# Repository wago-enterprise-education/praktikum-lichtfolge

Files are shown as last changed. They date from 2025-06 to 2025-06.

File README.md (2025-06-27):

# Praktikum – Lichtfolge

Bau einer kleinen Platine als handheld Spielekonsole.

- **Dauer:** ~20 Min. (ohne Auf- und Abbbauzeit)

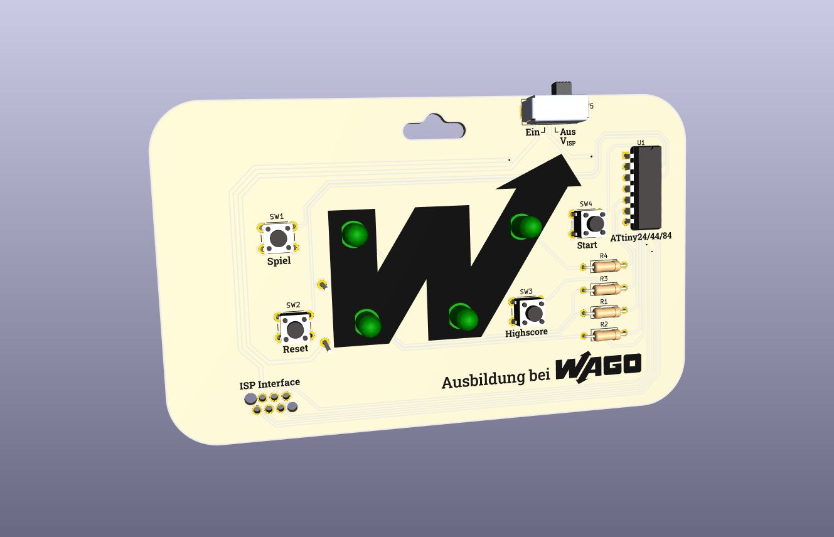
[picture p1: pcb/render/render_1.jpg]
Platine Praktikum-Lichtfolge
</br>

## Quick Links
- **Dokumentation:** [wago-enterprise-education.github.io/praktikum-lichtfolge/](https://wago-enterprise-education.github.io/praktikum-lichtfolge/)
- **Bestückungsplan:** [docs/Bestueckungsplan_praktikum-lichtfolge_v1.0.html](https://wago-enterprise-education.github.io/praktikum-lichtfolge/Bestueckungsplan_praktikum-lichtfolge_v1.0.html)
- **Schaltplan:** [pcb/schematics_praktikum-lichtfolge.pdf](pcb/schematics_praktikum-lichtfolge.pdf)
- **Materialliste (BOM):** [docs/bom/ibom_praktikum-lichtfolge_v1.0.html](https://wago-enterprise-education.github.io/praktikum-lichtfolge/bom/ibom_praktikum-lichtfolge_v1.0.html)

## Ansprechpartner
- [Tobias Lauxtermann](mailto:tobias.lauxtermann@wago.com)

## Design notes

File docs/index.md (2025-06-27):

---
layout: post
title: Praktikum – Lichtfolge
lang: de
---

# Praktikum – Lichtfolge

1. [Bauanleitung](#bauanleitung) 
2. [Upload des Programmcodes](#upload-des-programmcodes)
3. [Programming Guide](#programming-guide)

## Bauanleitung

{:.info}
Einen interaktiven Bestückungsplan mit Bauteilliste findest du hier: **[Bestückungsplan ➡️](Bestueckungsplan_praktikum-lichtfolge_v1.0.html)**

Beginne beim Bestücken und anschließenden Löten der Platine mit den **niedrigsten Bauteilen**. Sonst kann es eventuell schwierig werden diese später zu erreichen. Bei dieser Platine ist es wichtig den **Batteriehalter auf der Rückseite als letztes** einzubauen, da anschließend einige Lötstellen nicht mehr erreichbar sind. Dies ist auch das einzige Bauteil, das nicht auf der Vorderseite bestückt wird.

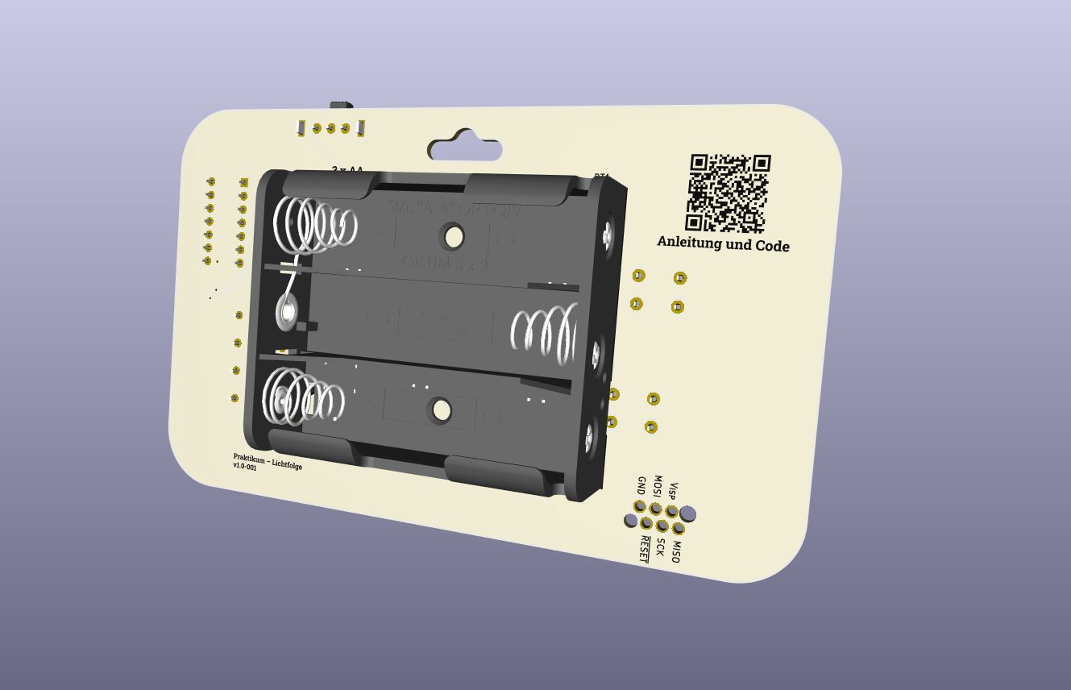
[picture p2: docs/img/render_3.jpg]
Platine Praktikum-Lichtfolge

Gelötet wird bei THT-Bauteilen (Through Hole Technology, deutsch Durchsteckmontage) immer auf der Nicht-Bestückungsseite. Also muss die Platine nach dem Einsetzen einmal gedreht werden. Damit die Bauteile dabei nicht herausfallen, sollten die Komponenten provisorisch fixiert werden. Manche Platinenhalter haben dafür bereits eine Vorrichtung (vgl. Abb.). Eine einfache Alternative ist Malerkrepp (leicht lösbares Klebeband), das über die Bauteile geklebt wird. Dabei ist es sinnvoll, **nicht alle Bauteile auf einmal** zu bestücken und anschließend zu löten, sondern in Gruppen ähnlicher und benachbarter Komponenten zu arbeiten. Die Taster und der Schiebeschalter auf dieser Platine müssen zum Löten nicht fixiert werden.

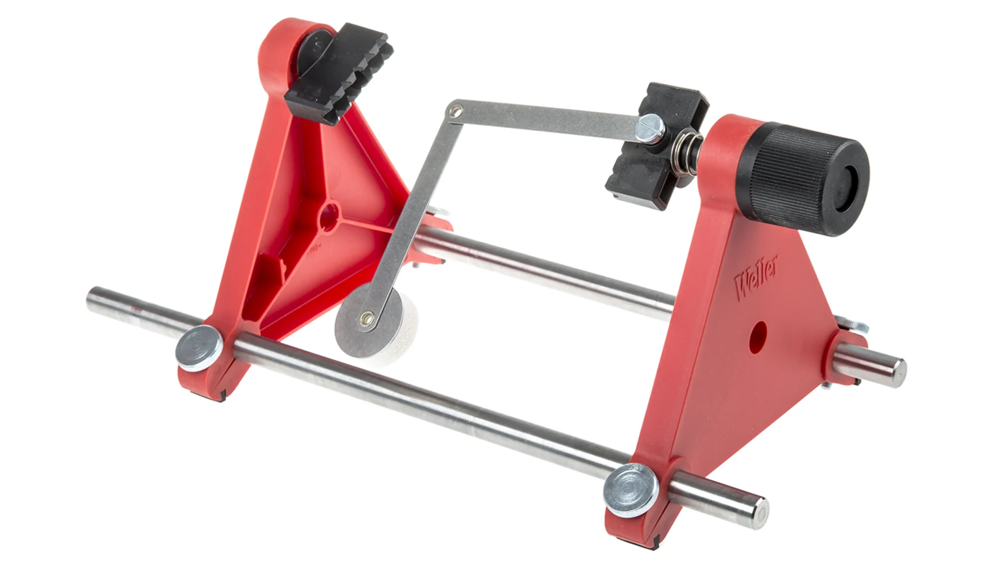
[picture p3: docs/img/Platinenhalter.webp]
Platinenhalter


Da wir bleifreies Lötzinn verwenden, sollte der Lötkolben etwas höher eingestellt werden. **330 bis 360°C** sind ein guter Richtwert. Für Lötstellen, die mit einer großen Kupferfläche verbunden sind, beispielsweise GND-Flächen, können auch 380°C sinnvoll sein. Mit steigender Temperatur sinkt jedoch die aktive Dauer des Flussmittels im Lötzinn deutlich, was wiederum das Löten erschwert. Mehr als 380°C sollten nicht eingestellt werden, da dies die Lebensdauer der Lötspitze stark verringert.

Achte beim Löten darauf zunächst **das Lötpad auf der Platine und das Beinchen des entsprechenden Bauteils gleichzeitig zu erhitzen** und erst nach einigen Sekunden Lötzinn hinzuzugeben. Geduldig sein sorgt hier für bessere Ergebnisse. Halte anschließend den Lötkolben noch kurz an die Lötstelle bis das Lötzinn schön geflossen und das gesamte Lötpad bedeckt ist. Sollte das hinzugegebene Lötzinn nicht ausreichen, kann hier auch noch etwas nachgeführt werden. 

Anschließend können mit einem Seitenschneider die überstehenden Drähte abgeknipst werden. Achte darauf dies nicht zu tief zu tun und **nur das Beinchen zu durchtrennen**, nicht die Lötstelle.

Bevor der Batteriehalter auf der Rückseite eingesetzt wird (dieser wird entsprechend auf der Vorderseite verlötet), klebe etwas **doppelseitiges Schaumstoffklebeband** darauf, um für zusätzliche mechanische Stabilität und Abstand zu den anderen Lötstellen zu sorgen.

## Upload des Programmcodes

{:.info}
**[Programmcode herunterladen ➡️](https://github.com/wago-enterprise-education/praktikum-lichtfolge/blob/main/code/praktikum-lichtfolge/praktikum-lichtfolge.ino)**

Die Platine verwendet für die Spiellogik einen Mikrocontroller aus der [ATtinyx4A ↗️](https://ww1.microchip.com/downloads/en/DeviceDoc/ATtiny24A-44A-84A-DataSheet-DS40002269A.pdf){:target="_blank" rel="noopener"} Reihe. Um genügend Speicherplatz für mehrere Spiele bereitzustellen, kommt der **ATtiny84A** zum Einsatz. Die Mikrocontrollerreihe verfügt über einen internen Oszillator für den Prozessortakt und kann über ein ISP-Interface programmiert werden. Der Eingangsspannungsbereich beträgt 1,8 bis 5,5 V.

Programmieren kann man den Mikrocontroller beispielsweise über die MPLAB® X IDE von Microchip, aber auch über Tools wie avrdude oder Arduino.

Bei unseren Praktikumsmodulen verwenden wir die [Arduino IDE ↗️](https://www.arduino.cc/en/software/){:target="_blank" rel="noopener"}. Dabei handelt es sich um eine open source Entwicklungsumgebung mit einer großen und aktiven online Community mit vielen Ressourcen zum Lernen. Über den darin integrierten Boards Manager kann der [ATTinyCore ↗️](https://github.com/SpenceKonde/ATTinyCore){:target="_blank" rel="noopener"} installiert werden, der es ermöglicht AVR-basierte Mikrocontroller wie den ATtiny84A zu programmieren.

Dafür wird ein zusätzliches Gerät, ein **ISP-Programmer**, benötigt. Es kann jedoch auch beispielsweise ein Arduino Uno hierfür verwendet werden. Hier findest du eine Anleitung dazu: [Programming ATtiny with Arduino code ↗️](https://wolles-elektronikkiste.de/en/programming-attiny-with-arduino-code){:target="_blank" rel="noopener"}. Die entsprechenden ISP-Verbindungen sind auf der Rückseite der Platine gekennzeichnet an die du übergangsweise Kabel anlöten kannst. 

Für eine schnelle und unkomplizierte Programmierung wurde im WAGO Ausbildungsbereich zusätzlich ein [ISP UPDI Programmer](https://wago-enterprise-education.github.io/isp-updi-programmer/) als Aufsatz für einen Arduino Uno entwickelt. Über lötfreie Steckverbinder kann hiermit der Mikrocontroller auf der Platine programmiert werden.

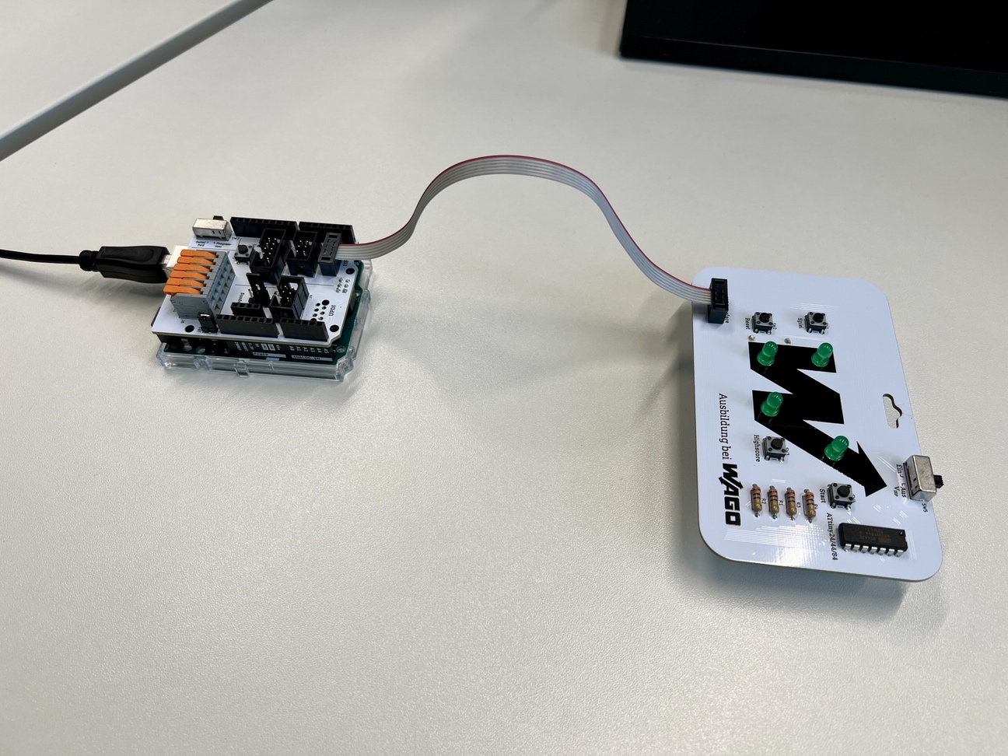
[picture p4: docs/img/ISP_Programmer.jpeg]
Programmierung über ISP


### Kurzanleitung
0. Falls nicht schon geschehen: AurduinoISP Sketch `File > Examples > 11.ArduinoISP > Arduino ISP` auf den Arduino Uno, Leonardo oder Mega laden. Beim WAGO ISP UPDI Programmer muss eventuell der linke Jumper entfernt werden. 
1. Arduino Projekt ([praktikum-lichtfolge](https://github.com/wago-enterprise-education/praktikum-lichtfolge/blob/main/code/praktikum-lichtfolge/praktikum-lichtfolge.ino)) öffnen
2. Mikrocontroller auswählen `Tools > Board: … > ATTinyCore > ATtiny24/44/84(a) (No bootloader)`
3. Standardeinstellungen können bestehen bleiben (vgl. Abb.)
4. `Tools > Programmer > Arduino as ISP` auswählen
5. `Tools > Port` und den COM-Port auswählen mit dem der Arduino verbunden ist
6. `Tools > Burn Bootloader` ausführen (muss bei Änderung der Clock Source erneut durchgeführt werden)
7. Upload (Pfeil oben links)

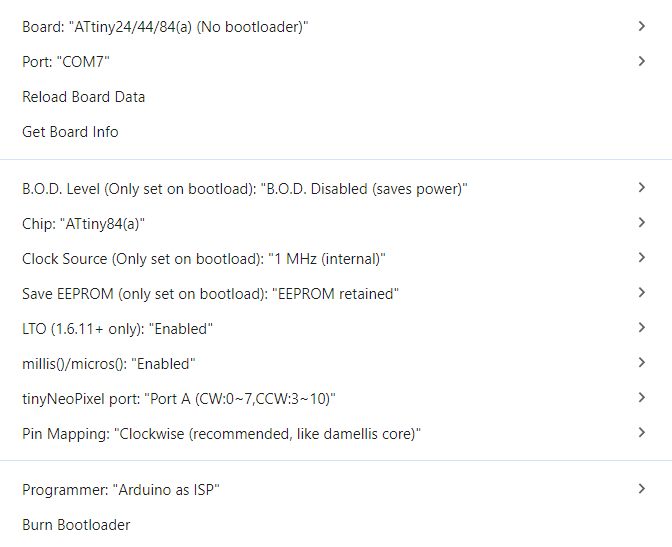
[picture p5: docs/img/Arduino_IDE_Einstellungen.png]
Einstellungen in der Arduino IDE


## Spielanleitung
Das UI (User Interface, deutsch Benutzeroberfläche) der Platine besteht aus 4 LEDs und 4 Tastern über die das Menü und die Spiele umgesetzt wurden. Im Folgenden wird kurz auf die verschiedenen Funktionen eingegangen.

### Spiel auswählen
Über **Taster 1 („Spiel“)** kann ein Spiel ausgewählt werden. Bei [Spiel 1](#spiele) muss sich eine immer länger werdende Lichtfolge gemerkt werden, [Spiel 2](#spiele) ist ein Reaktionsspiel, bei dem man möglichst schnell die LEDs „wegklicken“ muss, bei [Spiel 3](#spiele) handelt es sich um einen digitalen Würfel und [Spiel Nummer 4](#programmcode-für-spiel-4) ist frei. Hier kannst du mithilfe des [Programming Guides](#programming-guide) dein eigenes Spiel entwickeln. Selbstverständlich steht es dir aber frei alle Spiele anzupassen oder ganz auszutauschen.

### Spiel starten
Über **Taster 4 („Start“)** kann das aktuell ausgewählte Spiel gestartet werden.

### Highscore anzeigen
**Taster 3** zeigt den aktuellen Highscore des Spiels an. Jede LED steht dabei für die Ziffer einer vierstelligen Zahl. Blinkt beispielsweise LED 3 1-Mal und danach LED 4 6-Mal, beträgt der Highscore für dieses Spiel 16.

### Highscore zurücksetzen
Um den Highscore eines Spiels zurückzusetzen, halte **Taster 2 („Reset“)** mindestens 5 Sekunden gedrückt.

### Spiele

In der folgenden Tabelle werden die verfügbaren Spiele kurz erläutert.

|#| Spiel | Beschreibung |
|-|---|---|
|**1**|**Lichtfolge**|Nach einer kurzen Animation, um den Start des Spiels zu signalisieren, leuchtet eine zufällige LED auf. Merke dir diese und drücke den zugehörigen Taster. Anschließend leuchtet die gleiche LED erneut auf, gefolgt von einer weiteren zufälligen LED (es kann auch die gleiche noch mal sein). Daraufhin drückst du wieder nacheinander die entsprechenden Taster. Die Folge wird so immer länger, bis du dir die Reihenfolge nicht mehr merken kannst und einen Fehler machst. Dann blinken alle LEDs kurz viermal auf und dir wird deine erreichte Punktzahl angezeigt (siehe Unterkapitel [Highscore anzeigen](#highscore-anzeigen)). Die Punktzahl entspricht hierbei der Länge der Lichtfolge. Wieviel kannst du dir merken?|
|**2**|**Reaktionstest**|Zu Beginn des Spiels leuchtet eine zufällige LED auf. Klicke schnellstmöglich auf den entsprechenden Taster, um sie auszuschalten. Anschließend leuchtet eine beliebige andere LED auf. Du hast 30 Sekunden Zeit, um so möglichst viele LED „wegzuklicken“. Jede LED gibt hierbei einen Punkt. Drückst du jedoch versehentlich auf einen falschen Taster, wird dir ein Punkt abgezogen. Das Minimum sind jedoch 0 Punkte. Wie gut sind deine Reaktionen?|
|**3**|**Würfeln**|Nach einer kurzen Zufallsanimation leuchten alle vier LEDs ein paar Mal auf. Dies entspricht der gewürfelten Zahl zwischen 1 und 6. Im Code kannst du den Zahlenbereich aber auch anpassen oder die Art der Darstellung ändern, sodass die Zahlen wie bei den Highscores angezeigt werden. So könnten auch zufällige Zahlen von 0 bis 9999 angezeigt werden.|
|**4**|**Frei**|Hier kannst du dein eigenes Spiel programmieren. Informationen dazu findest du im [Programming Guide](#programming-guide).|

## Programming Guide
In diesem Kapitel gibt es eine kurze Einführung dazu, wie du **selbst Spiele für die Platine programmieren** kannst. Grundlagen für das Programmieren in C++ (Arduino) werden dabei vorausgesetzt. Bei YouTube gibt es ansonsten viele einsteigerfreundliche Tutorials dazu, suche einfach nach *Arduino Tutorial* und schon nach kurzer Zeit solltest du in der Lage sein die LEDs nach deinen Vorgaben anzusteuern.

### Programmcode für Spiel 4
In der Funktion `playGame4()` kannst du deinen eigenen Code schreiben. Sie wird ausgeführt, wenn LED 4 leuchtet und Taster 4 („Start“) gedrückt wird. Aktuell wird hier nur die Funktion `errorAnimation()` aufgerufen, die kurz alle LEDs viermal aufleuchten lässt. Entferne diese Funktion testweise und ersetzte sie durch `startupAnimation()`. Anschließend erscheint beim Starten des Spiels die Animation, die auch beim Einschalten der Platine angezeigt wird.

### LEDs ansteuern
Die LEDs können über die Funktion `digitalWrite()` ein- oder ausgeschaltet werden. Die entsprechenden Pins sind in dem Array `leds` hinterlegt.

Um beispielsweise LED 1 leuchten zu lassen, schreibe: `digitalWrite(leds[0], HIGH)`.

{:.info}
Den Schaltplan der Platine, um zu sehen welche Pins des Mikrocontrollers womit verbunden sind, findest du hier: **[Schaltplan Praktikum – Lichtfolge ➡️](https://github.com/wago-enterprise-education/praktikum-lichtfolge/blob/main/pcb/schematics_praktikum-lichtfolge.pdf)**

### Taster abfragen
Zum Entprellen der Taster wird die Bibliothek [Bounce2 ↗️](https://github.com/thomasfredericks/Bounce2){:target="_blank" rel="noopener"} verwendet. Das **Entprellen von Tastern und Schaltern** ist notwendig, da bei deren Betätigung kleine Vibrationen entstehen, die dafür sorgen, dass kurzzeitig zwischen geschlossenem und geöffnetem Zustand gewechselt wird. Erst nach einigen Millisekunden stabilisiert sich der Zustand. Beim schnellen Abfragen der Taster mit einem Mikrocontroller, kann es dadurch zu **ungewollten Zustandsänderungen** kommen, die mithilfe der Bibliothek herausgefiltert werden.

Die Instanzen für die jeweiligen Taster sind in dem Array `buttons` abgelegt. Um beispielsweise den Zustand von Taster 1 zu aktualisieren, muss regelmäßig die Funktion `buttons[0].update()` aufgerufen werden. Dies geschieht nicht automatisch im Hintergrund. Zwischen zwei Abfragen des Zustands eines Tasters, muss also mindestens einmal die Update-Funktion aufgerufen werden, um ein anderes Ergebnis erhalten zu können. Zum Aktualisieren von allen vier Tastern auf einmal, kann die Funktion `updateButtons()` genutzt werden.

Die Bounce2 Bibliothek stellt einige Funktionen bereit, die das Arbeiten mit den Tastern vereinfacht. Hier eine Liste der gängigsten Methoden:

| Funktion | Beschreibung |
|---|---|
|`pressed()`|Gibt „true“ zurück, wenn der Taster seit dem letzten Update gedrückt wurde, sich also der Zustand von „nicht-gedrückt“ zu „gedrückt“ geändert hat|
|`isPressed()`|Gibt „true“ zurück, wenn der Taster seit dem letzten Update gedrückt wurde, sich also der Zustand von „nicht-gedrückt“ zu „gedrückt“ geändert hat|
|`released()`|Gibt „true“ zurück, wenn der Taster aktuell gedrückt ist|
|`currentDuration()`|Gibt die Zeit zurück, wie lange der aktuelle Zustand herrscht|
|`read()`|Gibt den aktuellen Zustand (HIGH, LOW) des Tasters zurück. LOW = gedrückt, HIGH = nicht gedrückt.|

Die komplette Dokumentation findest du [hier ↗️](https://github.com/thomasfredericks/Bounce2){:target="_blank" rel="noopener"}.

### Weitere nützliche Funktionen und Variablen

| Funktion | Beschreibung |
|---|---|
|`startupAnimation()`|Zeigt die Start-Animation an|
|`errorAnimation()`|Zeigt die Error-Animation an|
|`clearLEDs()`|Setzt alle LEDs auf LOW|
|`random(long n)`|Gibt eine pseudo zufällige natürliche Zahl von 0 bis n-1 zurück|
|`displayScore(uint16_t score)`|Zeigt den „score“ mithilfe der LEDs an|
|`enum Buttons {GAME, RESET, HIGHSCORE, START}`|Bietet die Möglichkeit die Indizes der Taster über den Namen ihrer Funktion im Menü zu referenzieren (`GAME = 0`, `RESET = 1`, …)|
|`enum Game {SIMON_SAYS, WHACK_A_MOLE, ROLL_DICE, GAME4}`|Bietet die Möglichkeit die Indizes der Spiele über ihre Namen zu referenzieren (`SIMON_SAYS = 0`, …) |
|`displayHighscore(Game game)`|Zeige den Highscore des entsprechenden Spiels an|
|`updateHighscore(Game game, uint16_t score)`|Aktualisiert den Highscore, falls der „score“ größer ist als der bisherige Highscore|

### Beispielcode
```C++
void playGame4() {
  startupAnimation();
  updateButtons();
  delay(50);

  while(!buttons[RESET].pressed()) { // Das Ausrufezeichen negiert den darauffolgenden Ausdruck
    updateButtons();
    
    if(buttons[0].isPressed()) digitalWrite(leds[0], HIGH);
    else digitalWrite(leds[0], LOW);

    if(buttons[2].isPressed()) digitalWrite(leds[2], HIGH);
    else digitalWrite(leds[2], LOW);

    if(buttons[3].isPressed()) digitalWrite(leds[3], HIGH);
    else digitalWrite(leds[3], LOW);
  }
  errorAnimation();
  delay(250);
  startupAnimation();
}

```

Analysiere den Code und versuche herauszufinden, was die Funktion macht. **Lade anschließend das angepasste Projekt hoch** und überprüfe deine Ergebnisse.

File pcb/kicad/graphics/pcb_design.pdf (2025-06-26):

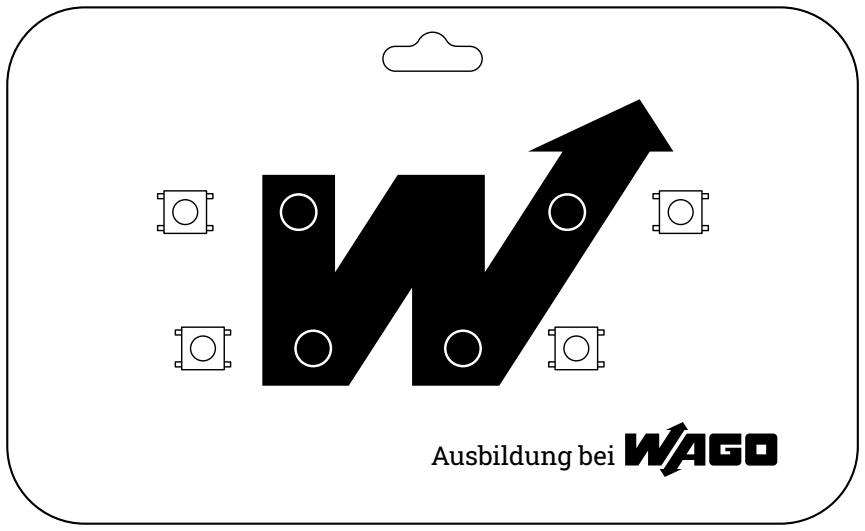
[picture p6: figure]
Ausbildung bei

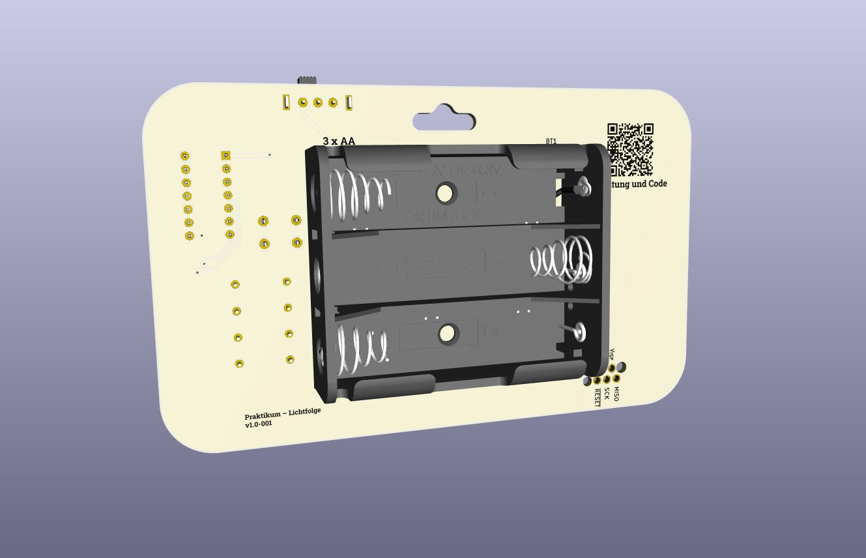
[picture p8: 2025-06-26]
pcb/render/render_4.jpg

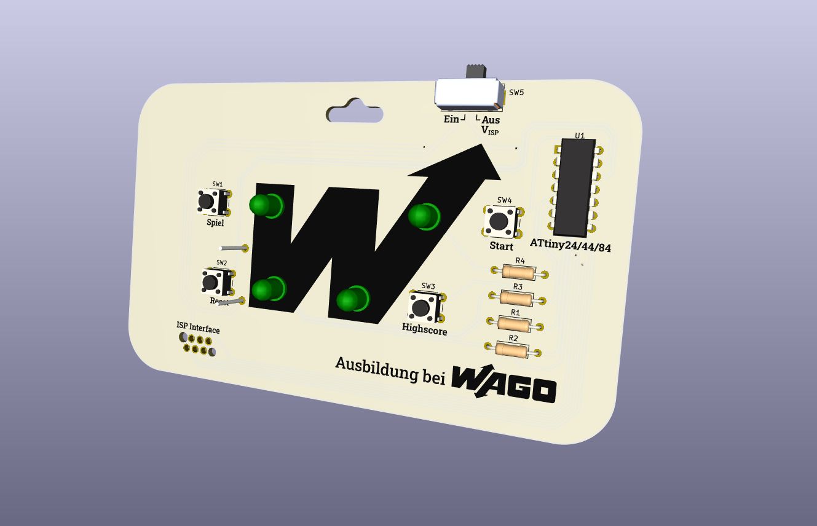
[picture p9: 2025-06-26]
pcb/render/render_2.jpg

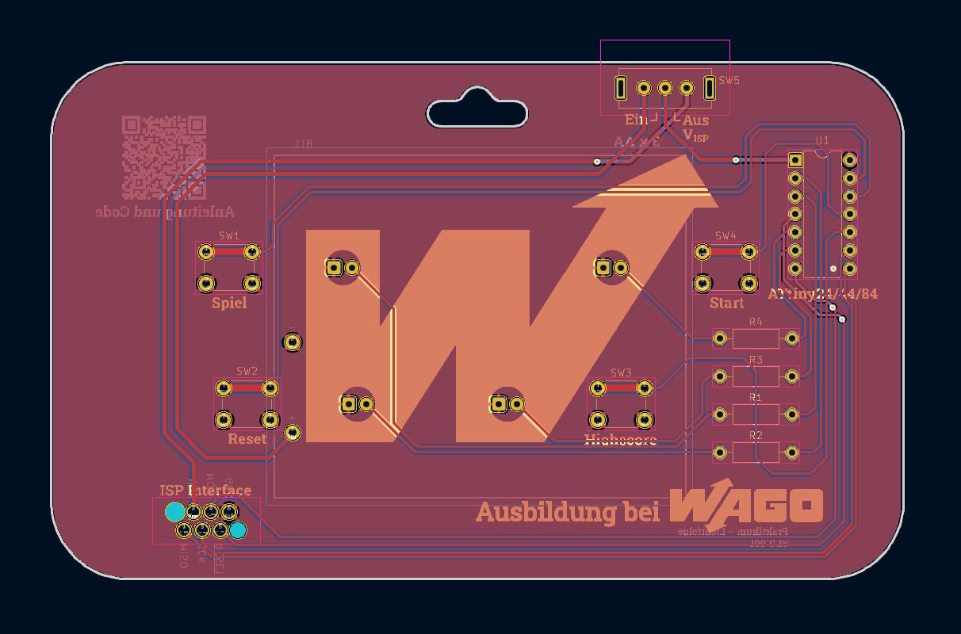
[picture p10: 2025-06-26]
pcb/layout/screenshot_pcb_layout_2_front_zone_fill.jpg

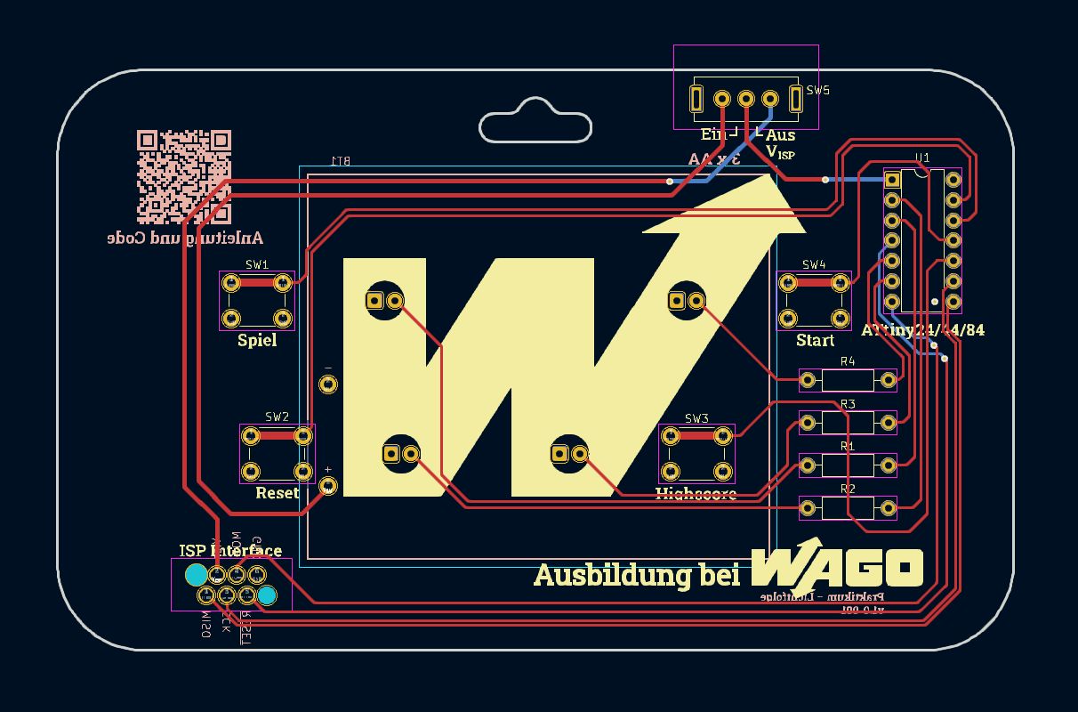
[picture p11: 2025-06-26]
pcb/layout/screenshot_pcb_layout_1.jpg

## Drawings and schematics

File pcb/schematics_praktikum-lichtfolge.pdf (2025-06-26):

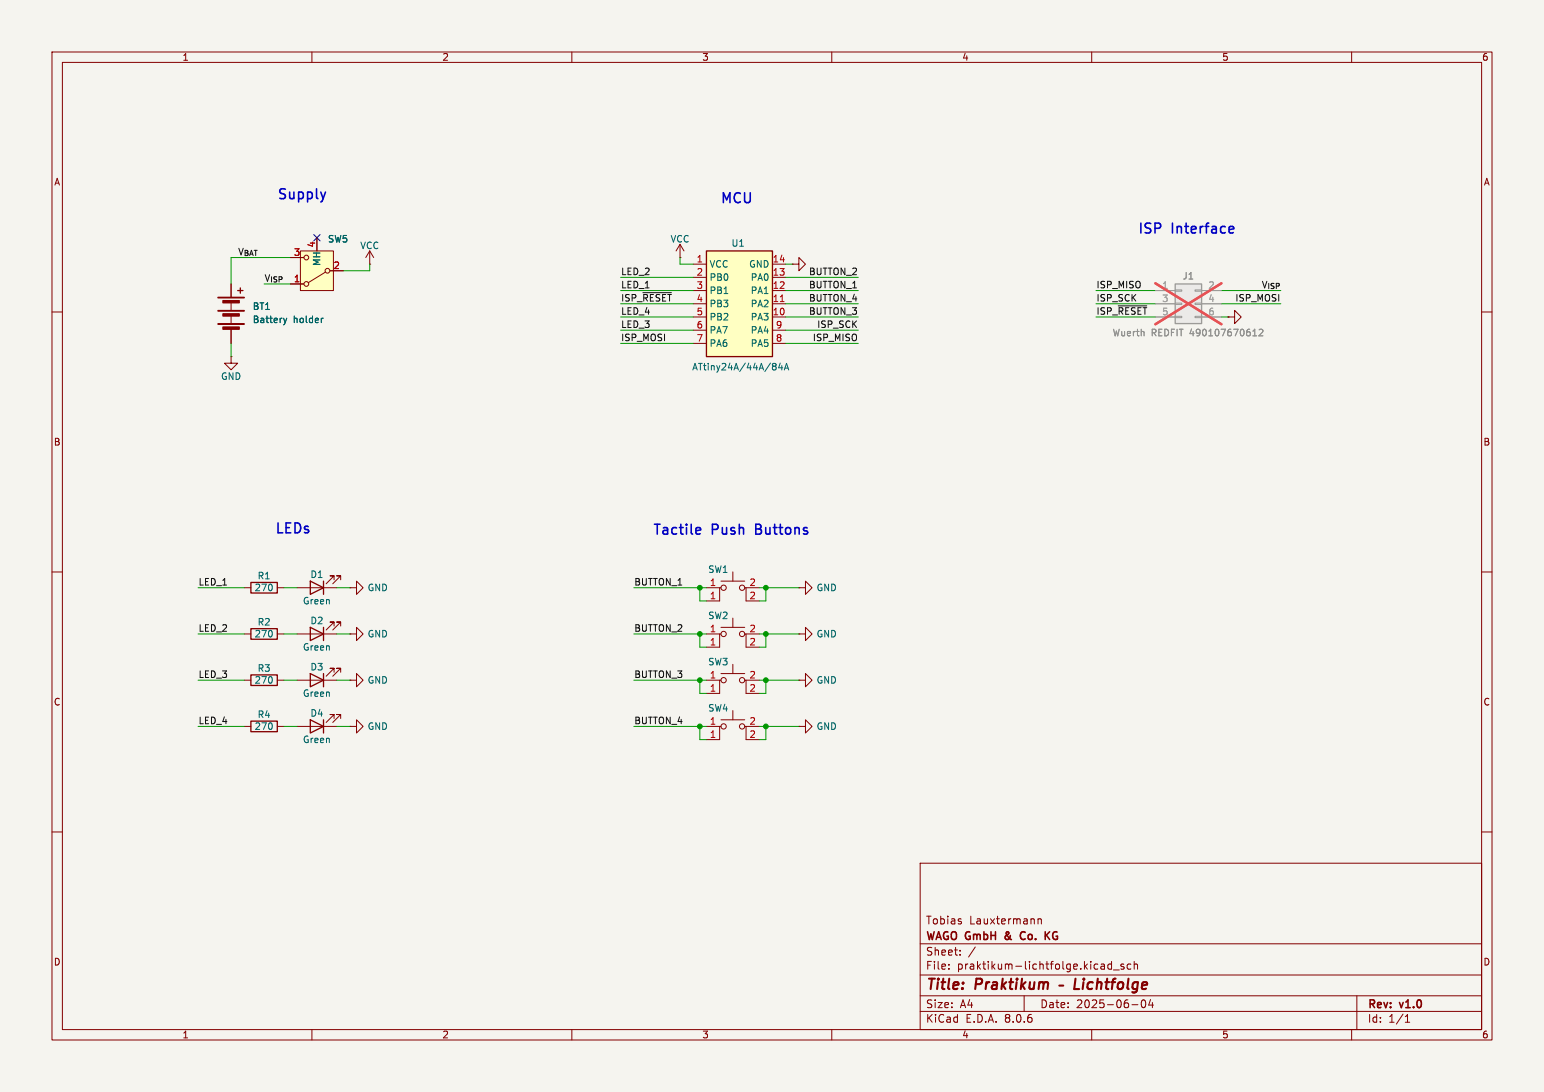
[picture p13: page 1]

Id: 1/1 Title: Praktikum þÿ Lichtfolge

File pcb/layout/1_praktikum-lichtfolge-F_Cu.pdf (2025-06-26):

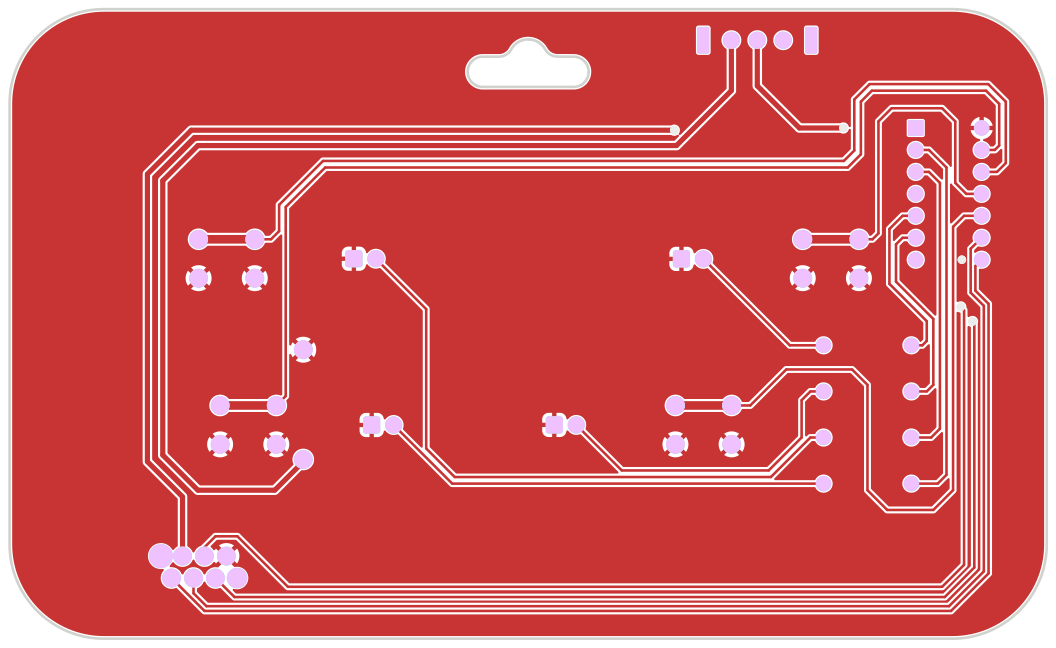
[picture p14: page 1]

Id: 1/1 Title: Praktikum þÿ Lichtfolge

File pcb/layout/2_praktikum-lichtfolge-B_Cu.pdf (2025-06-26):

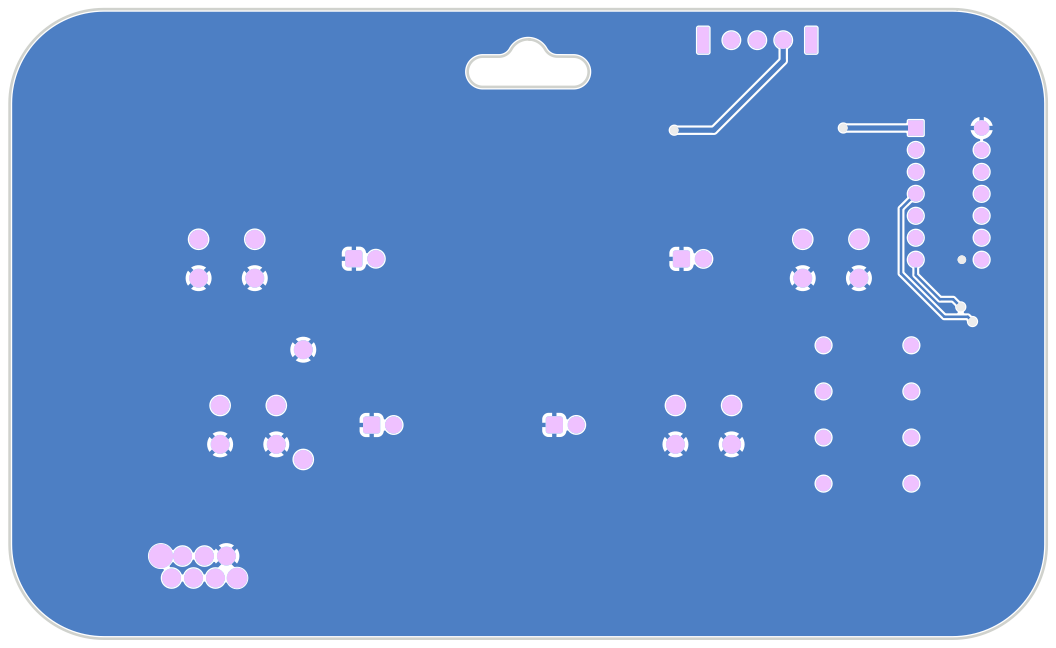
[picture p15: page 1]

Id: 1/1 Title: Praktikum þÿ Lichtfolge

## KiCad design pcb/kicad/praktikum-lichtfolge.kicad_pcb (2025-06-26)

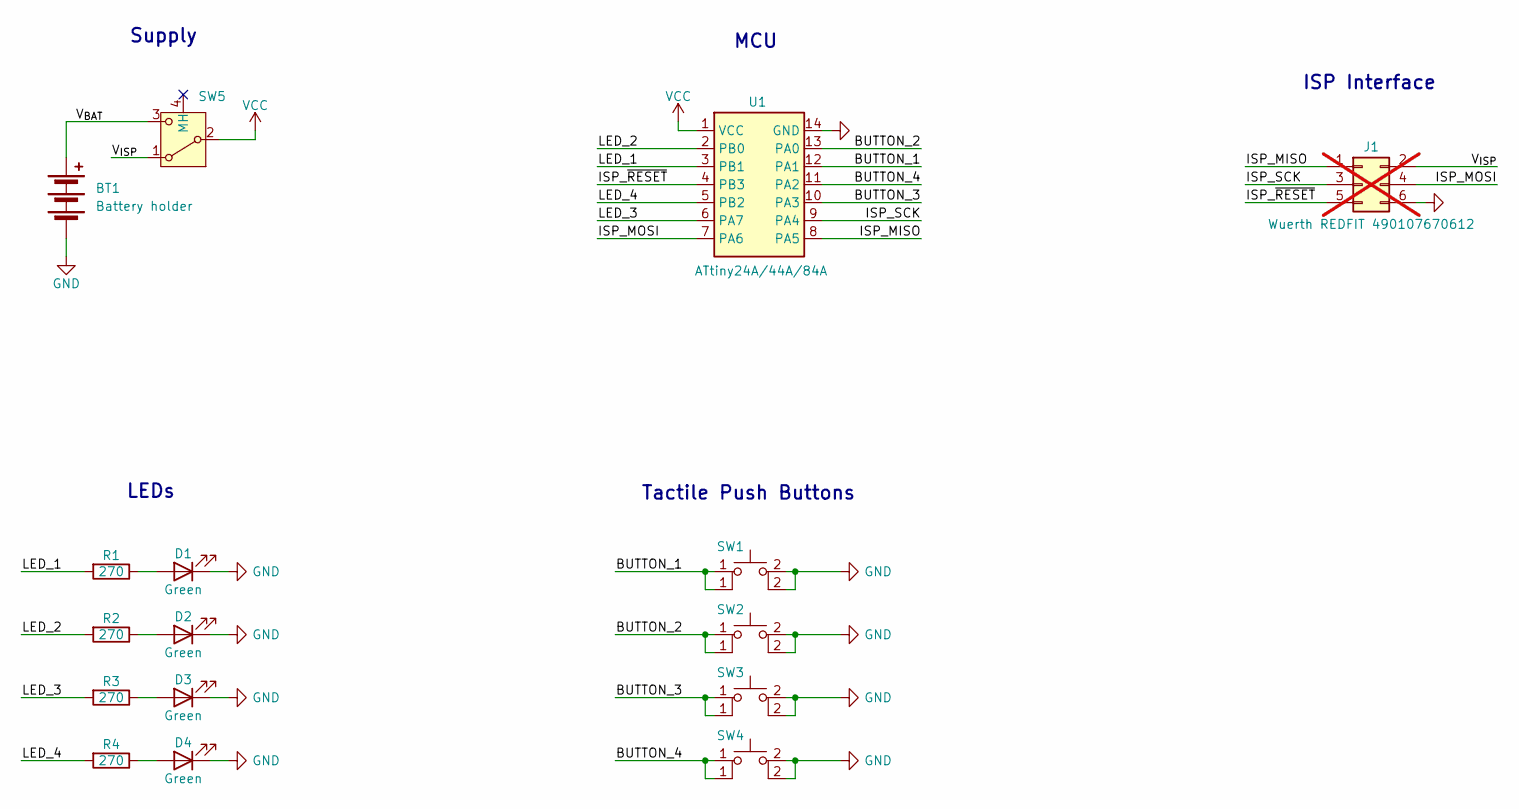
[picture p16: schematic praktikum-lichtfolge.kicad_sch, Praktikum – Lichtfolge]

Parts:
BT1: Battery holder; Keystone_3x_AA_battery_holder_2464; MPN 185-4644
D1, D2, D3, D4: Green; LED_D5.0mm; MPN L-53GD
J1: Wuerth REDFIT 490107670612; Wuerth_REDFIT_490107670612; MPN 490107670612; not fitted
R1, R2, R3, R4: 270; R_Axial_DIN0207_L6.3mm_D2.5mm_P10.16mm_Horizontal; MPN CFR50J270R
SW1, SW2, SW3, SW4: SW_Tactile_6mm; SW_PUSH_6mm_H5mm; MPN 1825910-6
SW5: SPDT_slide_switch; MPN 1386942
U1: ATtiny24A/44A/84A; DIP-14_W7.62mm; MPN ATTINY84A-PU

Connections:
/BUTTON_1: SW1.1, U1.12 (PA1)
/BUTTON_2: SW2.1, U1.13 (PA0)
/BUTTON_3: SW3.1, U1.10 (PA3)
/BUTTON_4: SW4.1, U1.11 (PA2)
/ISP_MISO: J1.1, U1.8 (PA5)
/ISP_MOSI: J1.4, U1.7 (PA6)
/ISP_SCK: J1.3, U1.9 (PA4)
/ISP_~RESET: J1.5, U1.4 (PB3)
/LED_1: R1.2, U1.3 (PB1)
/LED_2: R2.2, U1.2 (PB0)
/LED_3: R3.2, U1.6 (PA7)
/LED_4: R4.2, U1.5 (PB2)
/V_{BAT}: BT1.1 (+), SW5.3
/V_{ISP}: J1.2, SW5.1
GND: BT1.2 (-), D1.1 (K), D2.1 (K), D3.1 (K), D4.1 (K), J1.6, SW1.2, SW2.2, SW3.2, SW4.2, U1.14 (GND)
unnamed: D1.2 (A), R1.1
unnamed: D2.2 (A), R2.1
unnamed: D3.2 (A), R3.1
unnamed: D4.2 (A), R4.1
VCC: SW5.2, U1.1 (VCC)

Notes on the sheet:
ISP Interface
Supply
LEDs
MCU
Tactile Push Buttons

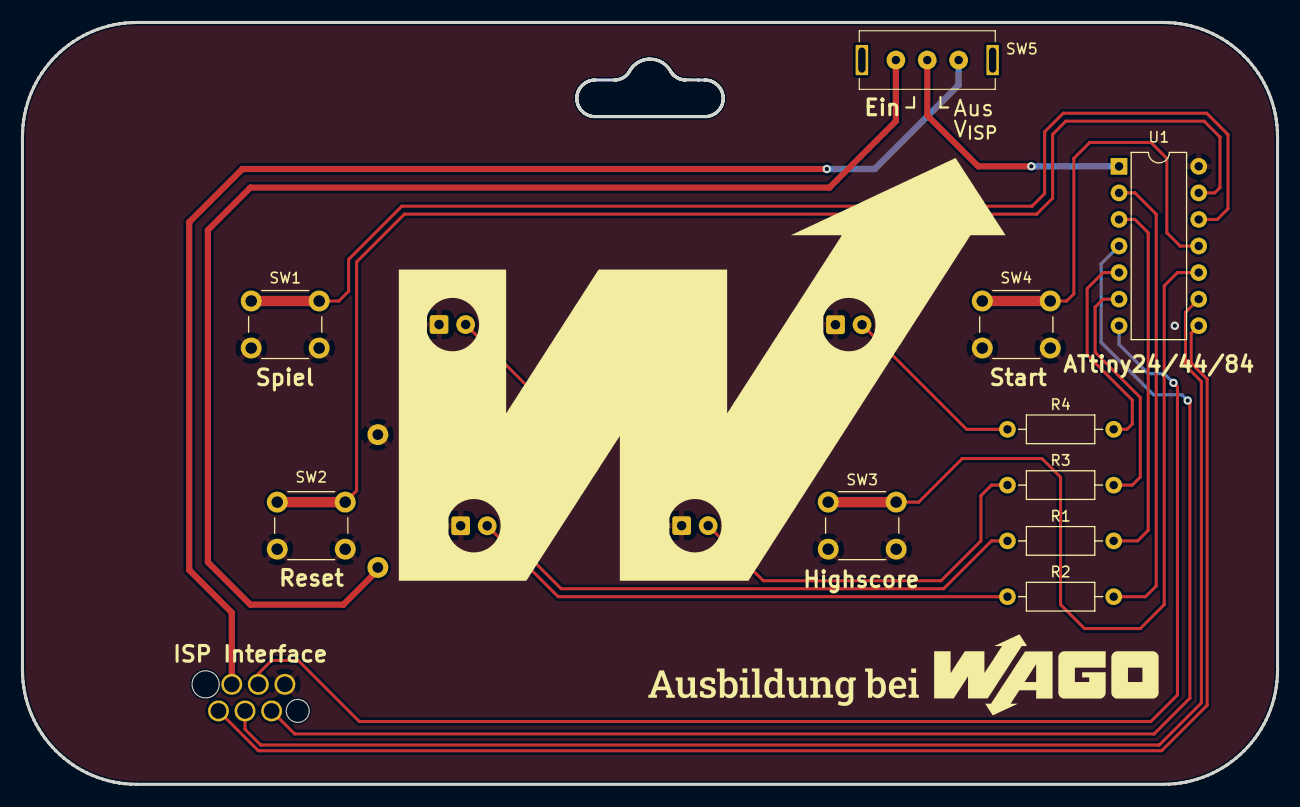
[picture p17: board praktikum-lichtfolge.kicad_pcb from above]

Board: 2 copper layers, 120.0 x 72.8 mm, 16 parts (1 on the bottom side), 20 nets.

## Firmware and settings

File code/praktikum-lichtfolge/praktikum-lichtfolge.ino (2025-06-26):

#include <Bounce2.h> // Library for debouncing buttons
#include <EEPROM.h> // Use EEPROM to store highscores

#define EEPROM_INIT_ADDRESS 0 // EEPROM address for the init marker, to set the EEPROM to 0 at first boot
#define EEPROM_INIT_MARKER 0x42
#define EEPROM_START_ADDRESS 1 // Start address to store the highscores (first address after init marker)

// All timing values in ms
#define RESET_BUTTON_PRESS_DURATION 3000 // Nesscesary time to hold the reset button

#define SIMON_SAYS_START_ON_TIME 400 // On time of the LEDs for the first sequence
#define SIMON_SAYS_PAUSE_TIME 150 // LED off time before the next LED in the sequence lights up to allow the same LED to light up again
#define SIMON_SAYS_DECREMENT_TIME 10 // Time decrement after each sequence
#define SIMON_SAYS_MIN_ON_TIME 250 // Minmum LED on time
#define SIMON_SAYS_SEQ_LEN 64 // Max sequence length
#define SIMON_SAYS_CHECK_LED_ON_TIME 450 // LED on time as feedback when the user enters the sequence

#define WHACK_A_MOLE_GAME_DURATION 30000

// Pin assignments (see Pinout_x4.jpg)
uint8_t leds[] = {PIN_PB1, PIN_PB0, PIN_PA7, PIN_PB2};
uint8_t buttonPins[] = {PIN_PA1, PIN_PA0, PIN_PA3, PIN_PA2};

/*
// Breadboard setup
uint8_t leds[] = {PIN_PA7, PIN_PB2, PIN_PB1, PIN_PB0};
uint8_t buttonPins[] = {PIN_PA3, PIN_PA2, PIN_PA1, PIN_PA0};
*/

Bounce2::Button buttons[4]; // Create 4 button objects

enum Buttons {GAME, RESET, HIGHSCORE, START};
enum Game {SIMON_SAYS, WHACK_A_MOLE, ROLL_DICE, GAME4};

Game selectedGame; // Global variable to store currently selected game

void setup() {
  initEEPROM(); // Reset EEPROM on first start

  // Seed the pseudo random number generator 
  pinMode(A1, INPUT); // Use ADC1 which is also PIN_PA1 where the first button is connected to since there is no unused pin left
  delay(100);
  uint16_t seedVal = analogRead(A1);
  while(seedVal == 0) { // Don't seed the pseudo random number generator as long as the button is pressed to prevent cheating
    delay(100);
    seedVal = analogRead(A1);
  }
  randomSeed(seedVal);

  // Setup the LEDs and buttons
  for(uint8_t i = 0; i < 4; i++) {
    pinMode(leds[i], OUTPUT);
    digitalWrite(leds[i], LOW);

    buttons[i] = Bounce2::Button();
    buttons[i].attach(buttonPins[i], INPUT_PULLUP); // INPUT_PULLUP for a defined state when the button is not beeing pressed
    buttons[i].interval(25); // Debounce interval. Physical buttons and switches bounce when they are pessed, filter these undesired state changes.
    buttons[i].setPressedState(LOW); // Pin is connected to GND (LOW) on the pcb when button is pressed
  }

  selectedGame = static_cast<Game>(0); // Always select the first game on startup. Could be changed and read from EEPROM to remember last game before switching off.

  startupAnimation();
}

void loop() {
  showMenu();
}

void showMenu() {
  updateButtons(); // Update button states. This must be called repetately.
  displayGame(selectedGame); // Display selected game using the corresponding LED

  if(buttons[GAME].pressed()) selectGame();
  else if(buttons[RESET].pressed()) resetHighscore(selectedGame);
  else if(buttons[HIGHSCORE].pressed()) displayHighscore(selectedGame);
  else if(buttons[START].pressed()) startGame(selectedGame);
}

void displayGame(Game game) {
  for(uint8_t i = 0; i < 4; i++) {
    digitalWrite(leds[i], (i == game) ? HIGH : LOW); // LED of corresponding LED HIGH if it's the selected game, otherwise LOW
  }
}

void selectGame() {
  selectedGame = static_cast<Game>((selectedGame + 1) % 4); // Select next game and go back to 0 if selectedGame > 3
}

void resetHighscore(Game game) {
  while(buttons[RESET].isPressed()) {
    buttons[RESET].update();
    if(buttons[RESET].currentDuration() >= RESET_BUTTON_PRESS_DURATION) {
      errorAnimation();
      clearHighscore(game);
      return; // If reset button is beeing pressed long enough, clear highscore in EEPROM and return to menu
    }
  }
}

void clearHighscore(Game game) {
  uint16_t address = EEPROM_START_ADDRESS + game * sizeof(uint16_t);
  EEPROM.put(address, 0);
}

uint16_t getHighscore(Game game) {
  uint16_t highscore;
  uint16_t address = EEPROM_START_ADDRESS + game * sizeof(uint16_t); 
  EEPROM.get(address, highscore);
  return highscore;
}

void updateHighscore(Game game, uint16_t score) {
  if(score > getHighscore(game)) { // Check if score is higher than current highscore
    if (score > 9999) { // Only scores up to 9999 can be displayed, if a score is higher, set to 9999
    score = 9999;
    }
    uint16_t address = EEPROM_START_ADDRESS + game * sizeof(uint16_t); // EEPROM.write() can only save 8 bits (1 Byte). Calculate the correct address.
    EEPROM.put(address, score); // Use EEPROM.put() to write any datatype 
  }
}

void displayHighscore(Game game) {
  uint16_t highscore = getHighscore(game);
  if(highscore != 0) displayScore(highscore);
  else errorAnimation();
}

void displayScore(uint16_t score) {
  clearLEDs();
  delay(250);
  for (uint8_t i = 0; i < 4; i++) { // Each of the four LEDs represent a digit 
    uint8_t digit = (score / (uint16_t)pow(10, 3-i)) % 10;
    for (uint8_t j = 0; j < digit; j++) { // Blink that LED according to the current digit of the score
      digitalWrite(leds[i], HIGH);
      delay(250);
      digitalWrite(leds[i], LOW);
      delay(250);
    }
  }
}

void startGame(Game game) {
  updateButtons();
  clearLEDs();
  switch (game) {
    case SIMON_SAYS:
      playSimonSays();
      break;
    case WHACK_A_MOLE:
      playWhackAMole();
      break;
    case ROLL_DICE:
      playRollDice();
      break;
    case GAME4:
      playGame4();
      break;
  }
  showMenu();
}

void playSimonSays() { // Repeat a given random sequence
  bool success = true;
  uint8_t seq[SIMON_SAYS_SEQ_LEN]; // Array to store the sequence
  uint8_t seqLen = 0; // and a variable to store the current length
  uint16_t onTime = SIMON_SAYS_START_ON_TIME;

  startupAnimation();
  delay(500);

  while(success) { // As long as the sequence is correct
    seq[seqLen] = random(4); // add a random LED (0 - 3)
    seqLen++;

    displaySequence(seq, seqLen, onTime);
    if(onTime - SIMON_SAYS_DECREMENT_TIME >= SIMON_SAYS_MIN_ON_TIME) onTime -= SIMON_SAYS_DECREMENT_TIME; // Sequence gets faster each round
    else onTime = SIMON_SAYS_MIN_ON_TIME;

    success = checkSequence(seq, seqLen); // User inputs the sequence
    if(success) {
      if(seqLen == SIMON_SAYS_SEQ_LEN) { // Stop if maxium length is reached
        seqLen++;
        break;
      }
      delay(SIMON_SAYS_CHECK_LED_ON_TIME);
      clearLEDs();
      delay(250);
    }
  }
  errorAnimation();
  delay(250);
  updateHighscore(SIMON_SAYS, seqLen - 1);
  displayScore(seqLen - 1);
  delay(500);
  startupAnimation();
}

void displaySequence(uint8_t seq[], uint8_t seqLen, uint16_t onTime) { // Display the sequence
  clearLEDs();
  for(uint8_t i = 0; i < seqLen; i++) {
    delay(SIMON_SAYS_PAUSE_TIME);
    digitalWrite(leds[seq[i]], HIGH);
    delay(onTime);
    digitalWrite(leds[seq[i]], LOW);
  }
}

bool checkSequence(uint8_t seq[], uint8_t seqLen) { // Check if the user correctly inputs the sequence
  uint8_t seqPos = 0;
  bool seqCorrect = true;
  uint32_t ledStartTime; // Variable to store the time the corresponding LED lit up as feedback for the user

  while(seqCorrect && seqPos < seqLen) {
    updateButtons();

    for (uint8_t i = 0; i < 4; i++) { // Check each button state
      if(buttons[i].pressed()) {
        clearLEDs(); // Also turn off last LED when a new button is pressed
        digitalWrite(leds[i], HIGH);
        ledStartTime = millis();
        if(seq[seqPos] == i) seqPos++; // If the pressed button was correct, go to next position in the sequence
        else seqCorrect = false;
      }
    }
    if(millis() - ledStartTime > SIMON_SAYS_CHECK_LED_ON_TIME) clearLEDs(); // Turn off LED time based
  }
  return seqCorrect;
}

void playWhackAMole() { // Click the correct button as fast as possible
  uint32_t startTime = millis();
  uint16_t score = 0;
  uint8_t currentLED = random(4); // Start with a random LED

  startupAnimation();
  delay(500);

  while (millis() - startTime < WHACK_A_MOLE_GAME_DURATION) { // Stop the game when time is over
    digitalWrite(leds[currentLED], HIGH); // Light up the current LED

    updateButtons();

    for (uint8_t i = 0; i < 4; i++) { // Check all buttons
      if (buttons[i].pressed()) {
        if (i == currentLED) {
          score++;  // Increment score for the correct button press
          digitalWrite(leds[currentLED], LOW);  // Turn off the current LED

          // Select the next LED excluding the current one
          uint8_t nextLED = random(4);
          while (nextLED == currentLED) {
            nextLED = random(4);
          }
          currentLED = nextLED;
        } 
        else {
          // Decrease score for incorrect button press unless zero
          score = (score > 0) ? score - 1 : 0;
        }
      }
    }
    
    if(buttons[RESET].isPressed() && buttons[RESET].currentDuration() > 5000) break; // Quit the game by holding the reset button
  }

  // Display the score and update highscore after the game ends
  clearLEDs();
  errorAnimation();
  delay(250);
  updateHighscore(WHACK_A_MOLE, score);
  displayScore(score);
  delay(500);
  startupAnimation();
}

void playRollDice() { // Show a random number from 1 to 6
  uint8_t number = random(6) + 1;
  randomAnimation(ROLL_DICE, 15, 50, 1.15); // Animation to randomly light up LEDs with decreasing speed
  delay(400);
  for(uint8_t i = 0; i < number; i++) { // Turn all LEDs on and off
    for(uint8_t j = 0; j < 4; j++) {
      digitalWrite(leds[j], HIGH);
    }
    delay(250);
    for(uint8_t j = 0; j < 4; j++) {
      digitalWrite(leds[j], LOW);
    }
    delay(250);
  }
  delay(250);
}

void playGame4() {
  errorAnimation();
  // Put your game logic here
}

void updateButtons() { // Update state of all buttons
  for (uint8_t i = 0; i < 4; i++) {
    buttons[i].update();
  }
}

void clearLEDs() { // Clear all LEDs
  for(uint8_t i = 0; i < 4; i++) {
    digitalWrite(leds[i], LOW);
  }
}

void startupAnimation() { // Show a simple animation to make the UI more intuitive
  for(uint8_t i = 0; i < 4; i++) {
    digitalWrite(leds[i], HIGH);
    delay(150);
    digitalWrite(leds[i], LOW);
  }
  for(int8_t i = 2; i >= 0; i--) {
    digitalWrite(leds[i], HIGH);
    delay(150);
    digitalWrite(leds[i], LOW);
  }
}

void errorAnimation() {
  for(uint8_t i = 0; i < 4; i++) {
    for(uint8_t j = 0; j < 4; j++) {
      digitalWrite(leds[j], HIGH);
    }
    delay(100);
    for(uint8_t j = 0; j < 4; j++) {
      digitalWrite(leds[j], LOW);
    }
    delay(100);
  }
}

void randomAnimation(uint8_t currentLED, uint8_t num, uint16_t T_start, float decFactor) { 
  uint8_t lastLED = currentLED; // First LED to light up is not the current LED
  uint8_t nextLED = random(4);
  clearLEDs();

  for(uint8_t i = 0; i < num; i++) {
    while(nextLED == lastLED) {
      nextLED = random(4);
    }
    digitalWrite(leds[lastLED], LOW);
    digitalWrite(leds[nextLED], HIGH);
    lastLED = nextLED;

    // Exponentially slow down animation
    uint16_t delayTime = T_start * pow(decFactor, i);
    
    delay(delayTime);
  }
  delay(250);
  clearLEDs();
}

void initEEPROM() {
  if (EEPROM.read(EEPROM_INIT_ADDRESS) != EEPROM_INIT_MARKER) { // If init marker has not been set the microcontroller is new and contains random values in EEPROM
    resetEEPROM(); // Reset EEPROM
    EEPROM.write(EEPROM_INIT_ADDRESS, EEPROM_INIT_MARKER); // Set init marker
  }
}

void resetEEPROM() {
  for (uint16_t i = 0 ; i < EEPROM.length() ; i++) { // Set all bytes in EEPROM to 0
    EEPROM.write(i, 0);
  }
}
